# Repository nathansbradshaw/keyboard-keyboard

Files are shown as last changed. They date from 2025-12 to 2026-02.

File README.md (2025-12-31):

# Keyboard-keyboard

Keyboard-keyboard is a Hall-effect keyboard PCB. The design is based on the IBM Model M keyboard layout. But this is intended to be used as a gimicky musical keyboard.

## Acknowledgements

- Based on the work of 
  [peppapighs](https://github.com/peppapighs/HE60/tree/main) for the hall effect keyboard and [dcpedit](https://github.com/dcpedit/mod-mmm) for the Model M layout.

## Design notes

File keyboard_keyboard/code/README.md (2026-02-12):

# Getting Started with Embedded Rust

This guide will help you set up your environment for embedded development using Rust. We'll cover the installation of necessary tools and libraries, and show you how to flash your program to a microcontroller and debug it.

## Prerequisites

Ensure you have Rust installed on your system. If not, you can install it from the [official Rust website](https://www.rust-lang.org/tools/install).

## Required Libraries and Tools

1. **Add the Rust Target for ARM Cortex-M microcontrollers:**

   ```sh
   rustup target add thumbv7em-none-eabihf
   ```

2. **Add LLVM Tools:**

   ```sh
   rustup component add llvm-tools-preview
   ```

3. **Install cargo-binutils:**

   ```sh
   cargo install cargo-binutils
   ```

4. **Install cargo-embed (actually probe-rs):**

   https://probe.rs/docs/getting-started/installation/

   `cargo-embed` is used for flashing your program to the microcontroller and provides a basic debugger.

## Flashing Your Program

To flash your program to a microcontroller, navigate to your project directory in the terminal and run:

```sh
cargo xtask embed
```

This command reads your `Embed.toml` configuration file (if present) and flashes the program accordingly.

## Running the host example
```sh
cargo run -p host-target-tests --bin host-target-tests
```

## Setting Up the Debugger

### Linux

- Install `gdb-multiarch` to debug a wide range of architectures:

  ```sh
  sudo apt-get install gdb-multiarch
  ```

### Windows

- Download and install the [Arm GNU Toolchain](https://developer.arm.com/downloads/-/arm-gnu-toolchain-downloads). This package includes `arm-none-eabi-gdb`, which is the debugger for ARM microcontrollers.

### macOS

- Use Homebrew to install the ARM version of GDB:

  ```sh
  brew install arm-none-eabi-gdb
  ```

## Debugging Your Program

To start a debug session, you need a GDB server running for your specific microcontroller. This might be provided by `cargo embed`, OpenOCD, or JLinkGDBServer, depending on your setup.

1. **Start the GDB Server** (if not automatically started by `cargo embed`):

   This step varies depending on your hardware and the software you're using as a GDB server. Refer to your hardware's documentation or the documentation of the GDB server software.

2. **Connect to the GDB Server:**

   - For Linux and macOS, you can use `gdb-multiarch` or `arm-none-eabi-gdb` respectively.
   - For Windows, use the `arm-none-eabi-gdb` from the GNU Arm Toolchain.

   Open a terminal and run:

   ```sh
   gdb-multiarch target/thumbv7em-none-eabihf/debug/synth-phone-e-v2-rust
   ```

   Replace `gdb-multiarch` with `arm-none-eabi-gdb` if you're on Windows or macOS

3. **Inside GDB**, connect to the local GDB server:

   ```gdb
   target remote :1337
   ```

   The port `1337` is an example; use the port number on which your GDB server is running.

You're now ready to debug your program using GDB commands!

## Further Learning

- The [Embedded Rust Book](https://docs.rust-embedded.org/book/) is an excellent resource for learning more about embedded development with Rust.
- Check out [The Discovery Book](https://docs.rust-embedded.org/discovery/) for hands-on projects aimed at beginners.
- How the project is setup [Ferrous Systems Test Embedded App](https://ferrous-systems.com/blog/test-embedded-app/)

# File Structure
```
├── .cargo
│   └── config.toml # <- contains no build target, just command alias
├── .github
│   ├── workflows
│   │   ├── nightly.yml
│   │   ├── rustfmt.yml # <- linter
│   │   └── test.yml
├── .vscode
│   └── settings.json
├── Cargo.toml # <- outer Cargo workspace
├── autotune # <- auto tune library, can be run on host
│   ├── Cargo.toml
│   └── src
├── cross # <- Embedded workspace cannot be ran on host
│   ├── Cargo.toml # <- inner Cargo workspace
│   ├── memory.x
│   ├── .cargo
│   │   └── config.toml # <- build target for daisy seed
│   ├── app
│   ├── board
│   ├── Embed.toml
│   ├── self-tests
│   └── target
├── docs
│   ├── help.md
│   └── random_notes.md
├── host-target-tests 
│   ├── Cargo.toml
│   ├── src
│   └── tests
├── README.md
├── target
│   ├── CACHEDIR.TAG
│   └── debug
└── xtask
    ├── Cargo.toml
    └── src

```

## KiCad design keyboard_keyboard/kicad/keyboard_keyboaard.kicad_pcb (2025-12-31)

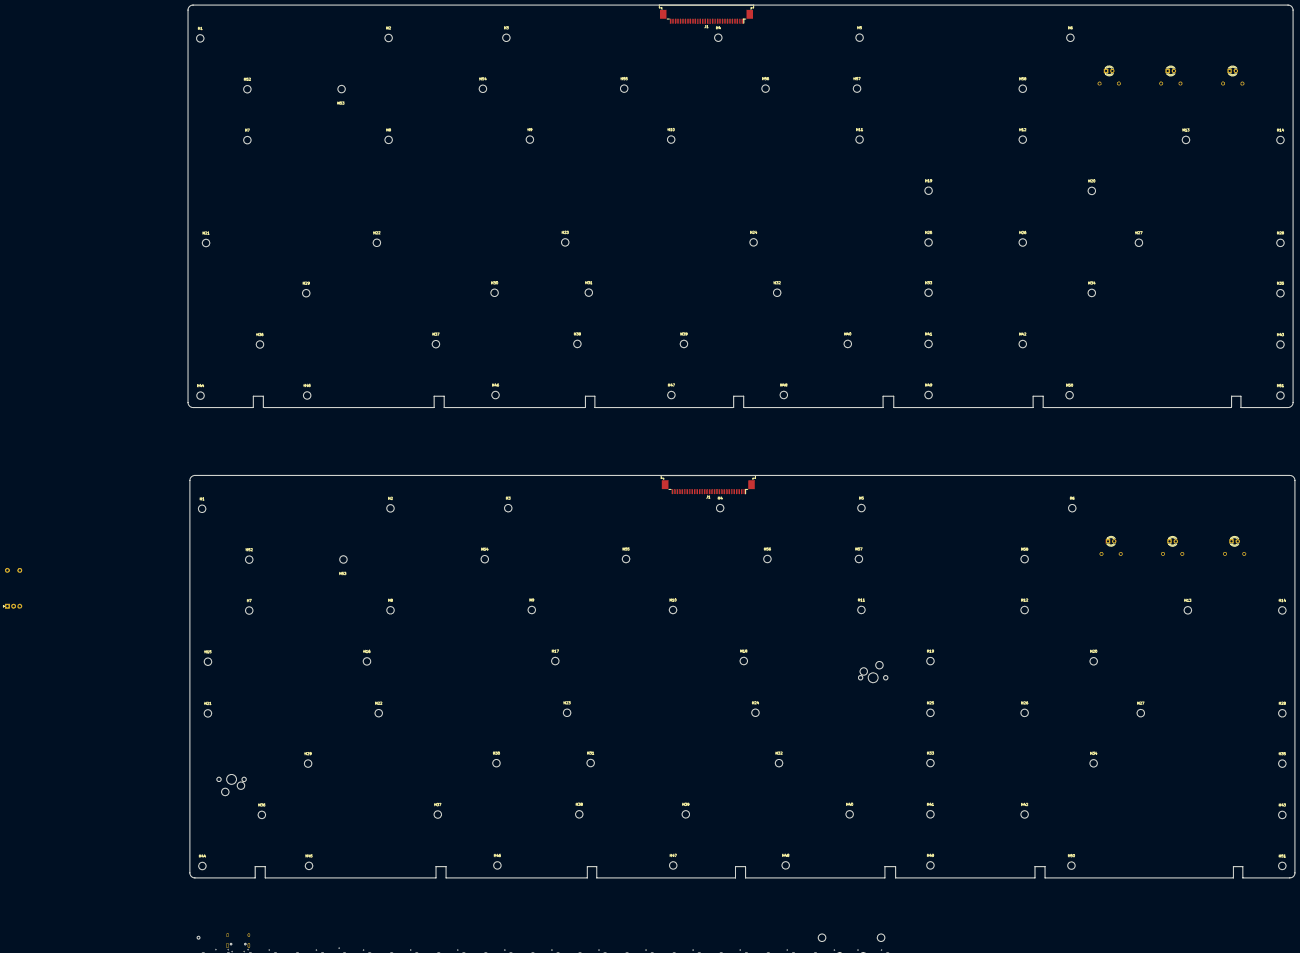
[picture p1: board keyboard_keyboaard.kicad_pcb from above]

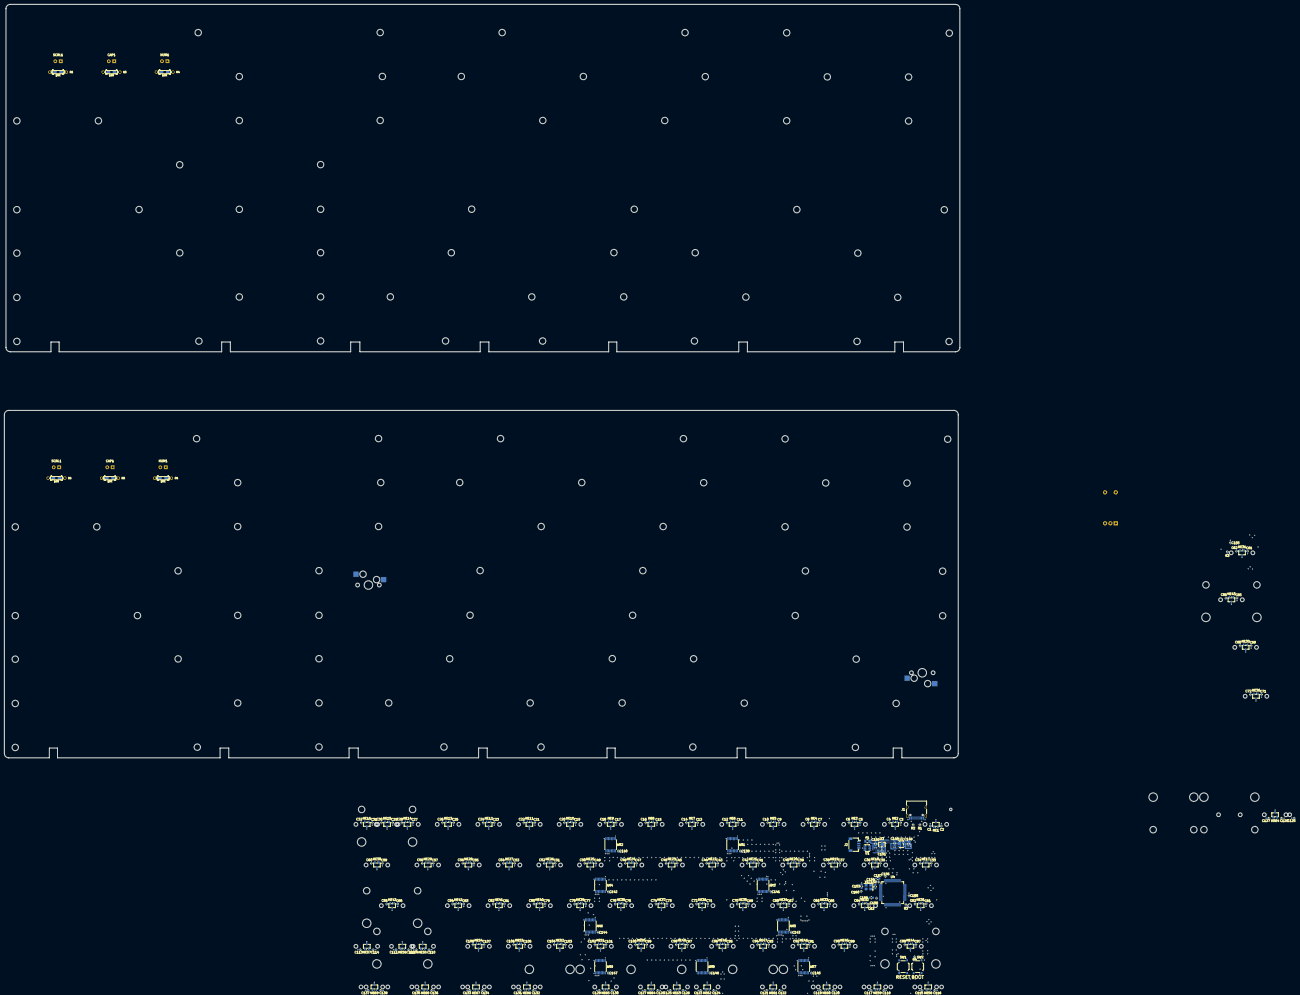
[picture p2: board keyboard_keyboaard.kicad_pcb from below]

Board: 2 copper layers, 447.8 x 353.1 mm, 484 parts (270 on the bottom side), 128 nets, no tracks yet.

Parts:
AM1, AM2, AM3, AM4, AM5, AM6, AM7, AM8, AM9: SN74LV4051A; TSSOP-16_4.4x5mm_P0.65mm
C1, C3, C5, C7, C9, C11, C13, C15, C17, C19, C21, C23, C25, C27, C29, C31, C33, C35, C37, C39, C41, C43, C45, C47, C49, C51, C53, C55, C57, C59, C59#2, C61, C61#2, C63, C65, C67, C69, C71, C71#2, C73, C75, C77, C79, C81, C83, C85, C85#2, C87, C89, C91, C93, C95, C97, C99, C101, C103, C105, C107, C109, C111, C113, C115, C117, C119, C121, C123, C125, C125#2, C127, C127#2, C129, C131, C133, C135, C137, C139, C140, C141, C142, C143, C144, C145, C146, C147, C154, C155, C155#2, C156, C158, C160: 100n; C_0402_1005Metric
C2, C4, C6, C8, C10, C12, C14, C16, C18, C20, C22, C24, C26, C28, C30, C32, C34, C36, C38, C40, C42, C44, C46, C48, C50, C52, C54, C56, C58, C60, C60#2, C62, C62#2, C64, C66, C68, C70, C72, C72#2, C74, C76, C78, C80, C82, C84, C86, C86#2, C88, C90, C92, C94, C96, C98, C100, C102, C104, C106, C108, C110, C112, C114, C116, C118, C120, C122, C124, C126, C128, C128#2, C130, C132, C134, C136, C138: 4.7n; C_0402_1005Metric
C148, C149, C150, C151: 2.2u; C_0603_1608Metric
C152, C153: 30p; C_0603_1608Metric
C157: 10u; C_0603_1608Metric
C159: 1u; C_0603_1608Metric
CAP1, CAP1#2: LED; LED_D3.0mm
F1: BSMD0805-050-24V; Fuse_0805_2012Metric
H1, H1#2, H2, H2#2, H3, H3#2, H4, H4#2, H5, H5#2, H6, H6#2, H7, H7#2, H8, H8#2, H9, H9#2, H10, H10#2, H11, H11#2, H12, H12#2, H13, H13#2, H14, H14#2, H15, H16, H17, H18, H19, H19#2, H20, H20#2, H21, H21#2, H22, H22#2, H23, H23#2, H24, H24#2, H25, H25#2, H26, H26#2, H27, H27#2, H28, H28#2, H29, H29#2, H30, H30#2, H31, H31#2, H32, H32#2, H33, H33#2, H34, H34#2, H35, H35#2, H36, H36#2, H37, H37#2, H38, H38#2, H39, H39#2, H40, H40#2, H41, H41#2, H42, H42#2, H43, H43#2, H44, H44#2, H45, H45#2, H46, H46#2, H47, H47#2, H48, H48#2, H49, H49#2, H50, H50#2, H51, H51#2, H52, H52#2, H53, H53#2, H54, H54#2, H55, H55#2, H56, H56#2, H57, H57#2, H58, H58#2: MountingHole; MountingHole_3mm
HE1, HE2, HE3, HE4, HE5, HE6, HE7, HE8, HE9, HE10, HE11, HE12, HE13, HE14, HE15, HE16, HE17, HE18, HE19, HE20, HE21, HE22, HE23, HE24, HE25, HE26, HE27, HE28, HE29, HE30, HE30#2, HE31, HE31#2, HE32, HE33, HE34, HE35, HE36, HE36#2, HE37, HE38, HE39, HE40, HE41, HE42, HE43, HE43#2, HE44, HE45, HE46, HE47, HE48, HE49, HE50, HE51, HE52, HE53, HE54, HE55, HE56, HE57, HE58, HE59, HE60, HE61, HE62, HE63, HE64, HE64#2, HE65, HE66, HE67, HE68, HE69: MT9102ET; SOT-23-3
J1, J1#2: Conn_01x30; TE_3-84952-0_1x30-1MP_P1.0mm_Horizontal
J1#3: TYPE-C-31-M-12; USB_C_Receptacle_HRO_TYPE-C-31-M-12
J2: JST_SH; JST_SH_SM04B-SRSS-TB_1x04-1MP_P1.00mm_Horizontal
MX1, MX2, MX3, MX4, MX5, MX6, MX7, MX8, MX9, MX10, MX11, MX12, MX13, MX14, MX16, MX18, MX19, MX20, MX21, MX22, MX23, MX24, MX25, MX26, MX27, MX28, MX29, MX32, MX33, MX34, MX35, MX36, MX36#2, MX37, MX38, MX39, MX40, MX41, MX42, MX45, MX46, MX47, MX48, MX49, MX50, MX51, MX52, MX53, MX54, MX57, MX61, MX64, MX69, MX73: 1U; MX-1U
MX15: 2U; MX-2U
MX17, MX30, MX30#2, MX59, MX63, MX71, MX75: 1.5U; MX-1.5U
MX31, MX31#2, MX55: 1.75U; MX-1.75U
MX040: MX-NoLED; MXOnly-1.25U-Hotswap
MX43, MX43#2, MX44: 2.25U; MX-2.25U
MX56: 2.75U; MX-2.75U
MX58, MX60, MX62, MX70, MX72, MX74, MX76: 1.25U; MX-1.25U
MX65: 2.25U; MX-2.25U-ReversedStabilizers
MX66, MX66#2: 6.25U; MX-6.25U-ReversedStabilizers
MX67, MX67#2: 7U; MX-7U-ReversedStabilizers
MX68, MX68#2: 2.75U; MX-2.75U-ReversedStabilizers
MX086: MX-NoLED; MXOnly-1.5U-Hotswap
NUM1, NUM1#2: LED; LED_D3.0mm
R1, R2: 5.1k; R_0402_1005Metric
R3, R3#2, R4#3: 12k; R_0402_1005Metric
R4, R4#2, R5, R5#2, R6, R6#2: 10K; Resistor-Hybrid-Back
SCRL1, SCRL1#2: LED; LED_D3.0mm
SW1, SW2: TS-1187A-B-A-B; SW_Push_1P1T_XKB_TS-1187A
SWR3: RotaryEncoder_Switch; RotaryEncoder_EC11_Nonplated
TH1, TH2: ToolingHole
U1: USBLC6-2SC6; SOT-23-6
U2: TLV75733PDBV; SOT-23-5
U3: XC6206P332MR-G; SOT-23-3
U4: AT32F405RCT7; LQFP-64_10x10mm_P0.5mm
Y1: X322512MSB4SI; Crystal_SMD_3225-4Pin_3.2x2.5mm

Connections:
+3.3V: C151.1, C154.1, C155.1, C155#2.1, C156.1, C157.1, SW2.2, U3.2 (VO), U4.1 (VDD), U4.36 (VDD), U4.64 (VDD)
+3.3VA: AM1.16 (VDD), AM2.16 (VDD), AM3.16 (VDD), AM4.16 (VDD), AM5.16 (VDD), AM6.16 (VDD), AM7.16 (VDD), AM8.16 (VDD), AM9.16 (VDD), C1.1, C3.1, C5.1, C7.1, C9.1, C11.1, C13.1, C15.1, C17.1, C19.1, C21.1, C23.1, C25.1, C27.1, C29.1, C31.1, C33.1, C35.1, C37.1, C39.1, C41.1, C43.1, C45.1, C47.1, C49.1, C51.1, C53.1, C55.1, C57.1, C59.1, C59#2.1, C61.1, C61#2.1, C63.1, C65.1, C67.1, C69.1, C71.1, C71#2.1, C73.1, C75.1, C77.1, C79.1, C81.1, C83.1, C85.1, C85#2.1, C87.1, C89.1, C91.1, C93.1, C95.1, C97.1, C99.1, C101.1, C103.1, C105.1, C107.1, C109.1, C111.1, C113.1, C115.1, C117.1, C119.1, C121.1, C123.1, C125.1, C125#2.1, C127.1, C127#2.1, C129.1, C131.1, C133.1, C135.1, C137.1, C139.1, C140.1, C141.1, C142.1, C143.1, C144.1, C145.1, C146.1, C147.1, C149.1, C158.1, C159.1, HE1.1 (VCC), HE2.1 (VCC), HE3.1 (VCC), HE4.1 (VCC), HE5.1 (VCC), HE6.1 (VCC), HE7.1 (VCC), HE8.1 (VCC), HE9.1 (VCC), HE10.1 (VCC), HE11.1 (VCC), HE12.1 (VCC), HE13.1 (VCC), HE14.1 (VCC), HE15.1 (VCC), HE16.1 (VCC), HE17.1 (VCC), HE18.1 (VCC), HE19.1 (VCC), HE20.1 (VCC), HE21.1 (VCC), HE22.1 (VCC), HE23.1 (VCC), HE24.1 (VCC), HE25.1 (VCC), HE26.1 (VCC), HE27.1 (VCC), HE28.1 (VCC), HE29.1 (VCC), HE30.1 (VCC), HE30#2.1 (VCC), HE31.1 (VCC), HE31#2.1 (VCC), HE32.1 (VCC), HE33.1 (VCC), HE34.1 (VCC), HE35.1 (VCC), HE36.1 (VCC), HE36#2.1 (VCC), HE37.1 (VCC), HE38.1 (VCC), HE39.1 (VCC), HE40.1 (VCC), HE41.1 (VCC), HE42.1 (VCC), HE43.1 (VCC), HE43#2.1 (VCC), HE44.1 (VCC), HE45.1 (VCC), HE46.1 (VCC), HE47.1 (VCC), HE48.1 (VCC), HE49.1 (VCC), HE50.1 (VCC), HE51.1 (VCC), HE52.1 (VCC), HE53.1 (VCC), HE54.1 (VCC), HE55.1 (VCC), HE56.1 (VCC), HE57.1 (VCC), HE58.1 (VCC), HE59.1 (VCC), HE60.1 (VCC), HE61.1 (VCC), HE62.1 (VCC), HE63.1 (VCC), HE64.1 (VCC), HE64#2.1 (VCC), HE65.1 (VCC), HE66.1 (VCC), HE67.1 (VCC), HE68.1 (VCC), HE69.1 (VCC), U2.5 (OUT), U4.13 (VDDA)
+5V: C148.1, C150.1, F1.2, U1.5 (VBUS), U2.1 (IN), U2.3 (EN), U3.3 (VI)
BOOT0: R4#3.1, SW2.1, U4.60 (PF11/BOOT0)
CAPS_LED: CAP1.2 (A), CAP1#2.2 (A), J1.29, J1#2.29
COL0: J1.28, J1#2.28, MX040.1 (COL)
COL1: J1.27, J1#2.27
COL2: J1.26, J1#2.26
COL3: J1.23, J1#2.23
COL4: J1.22, J1#2.22
COL5: J1.11, J1#2.11
COL6: J1.10, J1#2.10, MX086.1 (COL)
COL7: J1.7, J1#2.7
COL8: J1.5, J1#2.5
COL9: J1.4, J1#2.4
GND: AM1.6 (Inh), AM1.7 (VEE), AM1.8 (VSS), AM1.12 (X3), AM2.6 (Inh), AM2.7 (VEE), AM2.8 (VSS), AM3.2 (X6), AM3.6 (Inh), AM3.7 (VEE), AM3.8 (VSS), AM4.6 (Inh), AM4.7 (VEE), AM4.8 (VSS), AM5.6 (Inh), AM5.7 (VEE), AM5.8 (VSS), AM5.15 (X2), AM6.6 (Inh), AM6.7 (VEE), AM6.8 (VSS), AM7.6 (Inh), AM7.7 (VEE), AM7.8 (VSS), AM8.6 (Inh), AM8.7 (VEE), AM8.8 (VSS), AM9.6 (Inh), AM9.7 (VEE), AM9.8 (VSS), C1.2, C2.2, C3.2, C4.2, C5.2, C6.2, C7.2, C8.2, C9.2, C10.2, C11.2, C12.2, C13.2, C14.2, C15.2, C16.2, C17.2, C18.2, C19.2, C20.2, C21.2, C22.2, C23.2, C24.2, C25.2, C26.2, C27.2, C28.2, C29.2, C30.2, C31.2, C32.2, C33.2, C34.2, C35.2, C36.2, C37.2, C38.2, C39.2, C40.2, C41.2, C42.2, C43.2, C44.2, C45.2, C46.2, C47.2, C48.2, C49.2, C50.2, C51.2, C52.2, C53.2, C54.2, C55.2, C56.2, C57.2, C58.2, C59.2, C59#2.2, C60.2, C60#2.2, C61.2, C61#2.2, C62.2, C62#2.2, C63.2, C64.2, C65.2, C66.2, C67.2, C68.2, C69.2, C70.2, C71.2, C71#2.2, C72.2, C72#2.2, C73.2, C74.2, C75.2, C76.2, C77.2, C78.2, C79.2, C80.2, C81.2, C82.2, C83.2, C84.2, C85.2, C85#2.2, C86.2, C86#2.2, C87.2, C88.2, C89.2, C90.2, C91.2, C92.2, C93.2, C94.2, C95.2, C96.2, C97.2, C98.2, C99.2, C100.2, C101.2, C102.2, C103.2, C104.2, C105.2, C106.2, C107.2, C108.2, C109.2, C110.2, C111.2, C112.2, C113.2, C114.2, C115.2, C116.2, C117.2, C118.2, C119.2, C120.2, C121.2, C122.2, C123.2, C124.2, C125.2, C125#2.2, C126.2, C127.2, C127#2.2, C128.2, C128#2.2, C129.2, C130.2, C131.2, C132.2, C133.2, C134.2, C135.2, C136.2, C137.2, C138.2, C139.2, C140.2, C141.2, C142.2, C143.2, C144.2, C145.2, C146.2, C147.2, C148.2, C149.2, C150.2, C151.2, C152.2, C153.2, C154.2, C155.2, C155#2.2, C156.2, C157.2, C158.2, C159.2, C160.2, HE1.3 (GND), HE2.3 (GND), HE3.3 (GND), HE4.3 (GND), HE5.3 (GND), HE6.3 (GND), HE7.3 (GND), HE8.3 (GND), HE9.3 (GND), HE10.3 (GND), HE11.3 (GND), HE12.3 (GND), HE13.3 (GND), HE14.3 (GND), HE15.3 (GND), HE16.3 (GND), HE17.3 (GND), HE18.3 (GND), HE19.3 (GND), HE20.3 (GND), HE21.3 (GND), HE22.3 (GND), HE23.3 (GND), HE24.3 (GND), HE25.3 (GND), HE26.3 (GND), HE27.3 (GND), HE28.3 (GND), HE29.3 (GND), HE30.3 (GND), HE30#2.3 (GND), HE31.3 (GND), HE31#2.3 (GND), HE32.3 (GND), HE33.3 (GND), HE34.3 (GND), HE35.3 (GND), HE36.3 (GND), HE36#2.3 (GND), HE37.3 (GND), HE38.3 (GND), HE39.3 (GND), HE40.3 (GND), HE41.3 (GND), HE42.3 (GND), HE43.3 (GND), HE43#2.3 (GND), HE44.3 (GND), HE45.3 (GND), HE46.3 (GND), HE47.3 (GND), HE48.3 (GND), HE49.3 (GND), HE50.3 (GND), HE51.3 (GND), HE52.3 (GND), HE53.3 (GND), HE54.3 (GND), HE55.3 (GND), HE56.3 (GND), HE57.3 (GND), HE58.3 (GND), HE59.3 (GND), HE60.3 (GND), HE61.3 (GND), HE62.3 (GND), HE63.3 (GND), HE64.3 (GND), HE64#2.3 (GND), HE65.3 (GND), HE66.3 (GND), HE67.3 (GND), HE68.3 (GND), HE69.3 (GND), J1.1, J1.30, J1#2.1, J1#2.30, J1#3.A1 (GND), J1#3.A12 (GND), J1#3.B1 (GND), J1#3.B12 (GND), J1#3.S1 (SHIELD), J2.4, R1.2, R2.1, R3.1, R3#2.1, R4.2, R4#2.2, R4#3.2, R5.2, R5#2.2, R6.2, R6#2.2, SW1.2, U1.2 (GND), U2.2 (GND), U3.1 (GND), U4.12 (VSSA), U4.31 (VSS), U4.63 (VSS), Y1.2, Y1.4
HE1: AM3.15 (X2), C2.1, HE1.2 (OUT)
HE2: AM1.15 (X2), C4.1, HE2.2 (OUT)
HE3: AM1.14 (X1), C6.1, HE3.2 (OUT)
HE4: AM1.13 (X0), C8.1, HE4.2 (OUT)
HE5: AM1.1 (X4), C10.1, HE5.2 (OUT)
HE6: AM1.2 (X6), C12.1, HE6.2 (OUT)
HE7: AM1.4 (X7), C14.1, HE7.2 (OUT)
HE8: AM1.5 (X5), C16.1, HE8.2 (OUT)
HE9: AM2.1 (X4), C18.1, HE9.2 (OUT)
HE10: AM2.2 (X6), C20.1, HE10.2 (OUT)
HE11: AM2.4 (X7), C22.1, HE11.2 (OUT)
HE12: AM2.5 (X5), C24.1, HE12.2 (OUT)
HE13: AM2.15 (X2), C26.1, HE13.2 (OUT)
HE14: AM2.14 (X1), C28.1, HE14.2 (OUT)
HE15: AM2.13 (X0), C30.1, HE15.2 (OUT)
HE16: AM2.12 (X3), C32.1, HE16.2 (OUT)
HE17: AM3.14 (X1), C34.1, HE17.2 (OUT)
HE18: AM3.13 (X0), C36.1, HE18.2 (OUT)
HE19: AM3.12 (X3), C38.1, HE19.2 (OUT)
HE20: AM3.1 (X4), C40.1, HE20.2 (OUT)
HE21: AM3.4 (X7), C42.1, HE21.2 (OUT)
HE22: AM3.5 (X5), C44.1, HE22.2 (OUT)
HE23: AM4.1 (X4), C46.1, HE23.2 (OUT)
HE24: AM4.2 (X6), C48.1, HE24.2 (OUT)
HE25: AM4.4 (X7), C50.1, HE25.2 (OUT)
HE26: AM4.5 (X5), C52.1, HE26.2 (OUT)
HE27: AM4.15 (X2), C54.1, HE27.2 (OUT)
HE28: AM4.14 (X1), C56.1, HE28.2 (OUT)
HE29: AM4.13 (X0), C58.1, HE29.2 (OUT)
HE30: AM4.12 (X3), C60.1, C60#2.1, HE30.2 (OUT), HE30#2.2 (OUT)
HE31: AM7.1 (X4), C62.1, C62#2.1, HE31.2 (OUT), HE31#2.2 (OUT)
HE32: AM5.1 (X4), C64.1, HE32.2 (OUT)
HE33: AM5.2 (X6), C66.1, HE33.2 (OUT)
HE34: AM5.4 (X7), C68.1, HE34.2 (OUT)
HE35: AM5.5 (X5), C70.1, HE35.2 (OUT)
HE36: AM5.14 (X1), C72.1, C72#2.1, HE36.2 (OUT), HE36#2.2 (OUT)
HE37: AM5.13 (X0), C74.1, HE37.2 (OUT)
HE38: AM5.12 (X3), C76.1, HE38.2 (OUT)
HE39: AM6.1 (X4), C78.1, HE39.2 (OUT)
HE40: AM6.2 (X6), C80.1, HE40.2 (OUT)
HE41: AM6.4 (X7), C82.1, HE41.2 (OUT)
HE42: AM6.5 (X5), C84.1, HE42.2 (OUT)
HE43: AM6.15 (X2), C86.1, C86#2.1, HE43.2 (OUT), HE43#2.2 (OUT)
HE44: AM7.2 (X6), C88.1, HE44.2 (OUT)
HE45: AM7.4 (X7), C90.1, HE45.2 (OUT)
HE46: AM7.5 (X5), C92.1, HE46.2 (OUT)
HE47: AM8.1 (X4), C94.1, HE47.2 (OUT)
HE48: AM8.2 (X6), C96.1, HE48.2 (OUT)
HE49: AM8.4 (X7), C98.1, HE49.2 (OUT)
HE50: AM8.5 (X5), C100.1, HE50.2 (OUT)
HE51: AM9.1 (X4), C102.1, HE51.2 (OUT)
HE52: AM9.2 (X6), C104.1, HE52.2 (OUT)
HE53: AM9.4 (X7), C106.1, HE53.2 (OUT)
HE54: AM9.5 (X5), C108.1, HE54.2 (OUT)
HE55: AM6.12 (X3), C110.1, HE55.2 (OUT)
HE56: AM6.13 (X0), C112.1, HE56.2 (OUT)
HE57: AM6.14 (X1), C114.1, HE57.2 (OUT)
HE58: AM7.15 (X2), C116.1, HE58.2 (OUT)
HE59: AM7.14 (X1), C118.1, HE59.2 (OUT)
HE60: AM7.13 (X0), C120.1, HE60.2 (OUT)
HE61: AM7.12 (X3), C122.1, HE61.2 (OUT)
HE62: AM8.12 (X3), C124.1, HE62.2 (OUT)
HE63: AM8.13 (X0), C126.1, HE63.2 (OUT)
HE64: AM8.14 (X1), C128.1, C128#2.1, HE64.2 (OUT), HE64#2.2 (OUT)
HE65: AM8.15 (X2), C130.1, HE65.2 (OUT)
HE66: AM9.12 (X3), C132.1, HE66.2 (OUT)
HE67: AM9.13 (X0), C134.1, HE67.2 (OUT)
HE68: AM9.14 (X1), C136.1, HE68.2 (OUT)
HE69: AM9.15 (X2), C138.1, HE69.2 (OUT)
HEXT_IN: C152.1, U4.5 (PF0/HEXT_IN), Y1.1
HEXT_OUT: C153.1, U4.6 (PF1/HEXT_OUT), Y1.3
MUX_OUT_1: AM1.3 (X), U4.17 (PA3)
MUX_OUT_2: AM2.3 (X), U4.20 (PA4)
MUX_OUT_3: AM3.3 (X), U4.21 (PA5)
MUX_OUT_4: AM4.3 (X), U4.22 (PA6)
MUX_OUT_5: AM5.3 (X), U4.23 (PA7)
MUX_OUT_6: AM6.3 (X), U4.24 (PC4)
MUX_OUT_7: AM7.3 (X), U4.25 (PC5)
MUX_OUT_8: AM8.3 (X), U4.26 (PB0)
MUX_OUT_9: AM9.3 (X), U4.27 (PB1)
MUX_SELECT_0: AM1.11 (A), AM2.11 (A), AM3.11 (A), AM4.11 (A), AM5.11 (A), AM6.11 (A), AM7.11 (A), AM8.11 (A), AM9.11 (A), U4.9 (PC1)
MUX_SELECT_1: AM1.10 (B), AM2.10 (B), AM3.10 (B), AM4.10 (B), AM5.10 (B), AM6.10 (B), AM7.10 (B), AM8.10 (B), AM9.10 (B), U4.10 (PC2)
MUX_SELECT_2: AM1.9 (C), AM2.9 (C), AM3.9 (C), AM4.9 (C), AM5.9 (C), AM6.9 (C), AM7.9 (C), AM8.9 (C), AM9.9 (C), U4.11 (PC3)
NRST: C160.1, SW1.1, U4.7 (NRST)
NUM_LED: J1.3, J1#2.3, NUM1.2 (A), NUM1#2.2 (A)
unnamed: CAP1.1 (K), CAP1#2.1 (K), R5.1, R5#2.1
unnamed: J1#3.A5 (CC1), R1.1
unnamed: J1#3.B5 (CC2), R2.2
unnamed: NUM1.1 (K), NUM1#2.1 (K), R4.1, R4#2.1
unnamed: R6.1, R6#2.1, SCRL1.1 (K), SCRL1#2.1 (K)
unnamed: R3.2, R3#2.2, U4.33 (OTGHS1_R)
RE1: J1.9, J1#2.9
RE2: J1.8, J1#2.8
RE3: J1.6, J1#2.6
ROW0: J1.25, J1#2.25
ROW1: J1.21, J1#2.21
ROW2: J1.20, J1#2.20
ROW3: J1.19, J1#2.19
ROW4: J1.18, J1#2.18
ROW5: J1.17, J1#2.17
ROW6: J1.24, J1#2.24
ROW7: J1.16, J1#2.16
ROW8: J1.15, J1#2.15
ROW9: J1.14, J1#2.14
ROW10: J1.13, J1#2.13
ROW11: J1.12, J1#2.12
SCRL_LED: J1.2, J1#2.2, SCRL1.2 (A), SCRL1#2.2 (A)
USB_D+: U1.4 (I/O2), U4.35 (OTGHS1_D+)
USB_D-: U1.6 (I/O1), U4.34 (OTGHS1_D-)
USB_PLUG_D+: J1#3.A6 (D+), J1#3.B6 (D+), J2.3, U1.3 (I/O2)
USB_PLUG_D-: J1#3.A7 (D-), J1#3.B7 (D-), J2.2, U1.1 (I/O1)
VBUS: F1.1, J1#3.A4 (VBUS), J1#3.A9 (VBUS), J1#3.B4 (VBUS), J1#3.B9 (VBUS), J2.1

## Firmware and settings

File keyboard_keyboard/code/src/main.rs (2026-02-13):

//! hall_effect_keyboard — Daisy Seed + CD74HC4051 + A1302
//! Relative-threshold scanning with per-channel baseline calibration
//! MIDI output over USART1 at 31250 baud
#![no_main]
#![no_std]

use panic_rtt_target as _;

mod midi_sender;

#[rtic::app(
    device = stm32h7xx_hal::stm32,
    peripherals = true,
    dispatchers = [DMA1_STR2, DMA1_STR3, DMA1_STR4, DMA1_STR5, DMA1_STR6]
)]
mod app {
    const BLOCK_SIZE: usize = 128;
    const NUM_KEYS: usize = 8;
    const NUM_ACTIVE_KEYS: usize = 6;

    // Map each mux channel to a MIDI note number.
    const KEY_TO_NOTE: [u8; NUM_KEYS] = [48, 50, 52, 55, 57, 60, 62, 64];

    use crate::midi_sender::MidiSender;
    use libdaisy::gpio::*;
    use libdaisy::logger;
    use libdaisy::{audio, system};
    use stm32h7xx_hal::time::MilliSeconds;

    use libdaisy::hal::{
        adc::{self, Adc, AdcSampleTime, Resolution},
        gpio::{Analog, Output, PushPull},
        prelude::*,
        serial::{config::Config as SerialConfig, SerialExt},
        stm32,
        time::U32Ext,
        timer,
    };
    use log::info;

    // ── ADC config ─────────────────────────────────────────────────────────────
    const ADC_SAMPLE_TIME: AdcSampleTime = AdcSampleTime::T_16;
    const ADC_RESOLUTION: Resolution = Resolution::TwelveBit;

    // ── Calibration ────────────────────────────────────────────────────────────
    const CALIBRATION_SAMPLES: usize = 64;

    // ── Key thresholds (relative to per-channel baseline) ─────────────────────
    const FIRST_DELTA: u16 = 200;
    const SECOND_DELTA: u16 = 400;
    const RELEASE_DELTA: u16 = 150;

    // ── Debounce ───────────────────────────────────────────────────────────────
    // How many consecutive ticks a threshold must be exceeded before we act.
    // At 1kHz scan rate, 3 ticks = 3ms — filters out single-sample noise
    // spikes while adding negligible latency.
    const DEBOUNCE_TICKS: u8 = 3;

    // ── Moving average filter ──────────────────────────────────────────────────
    // Number of samples to average per channel. Must be a power of 2 for
    // efficient division. 4 samples = 4ms of smoothing at 1kHz.
    const FILTER_SIZE: usize = 4;
    const FILTER_SHIFT: u32 = 2; // log2(FILTER_SIZE)

    // ── Velocity ───────────────────────────────────────────────────────────────
    const VELOCITY_WINDOW_MS: u32 = 80;

    // ── Diagnostic logging ─────────────────────────────────────────────────────
    // Set to true to log raw ADC values every LOG_INTERVAL_MS.
    // Use this to see what your channels are doing at rest and find noise.
    const DIAG_LOGGING: bool = true;
    const LOG_INTERVAL_MS: u32 = 500;

    // ── Per-channel filter state ───────────────────────────────────────────────
    #[derive(Clone, Copy)]
    pub struct ChannelFilter {
        ring: [u16; FILTER_SIZE],
        index: usize,
        sum: u32,
    }

    impl ChannelFilter {
        const fn new() -> Self {
            Self {
                ring: [0; FILTER_SIZE],
                index: 0,
                sum: 0,
            }
        }

        /// Feed a new raw sample, return the filtered (averaged) value.
        fn feed(&mut self, raw: u16) -> u16 {
            // Subtract the oldest sample, add the new one
            self.sum -= self.ring[self.index] as u32;
            self.sum += raw as u32;
            self.ring[self.index] = raw;
            self.index = (self.index + 1) % FILTER_SIZE;
            (self.sum >> FILTER_SHIFT) as u16
        }

        /// Prime all slots with the same value (used after calibration).
        fn prime(&mut self, value: u16) {
            for slot in self.ring.iter_mut() {
                *slot = value;
            }
            self.sum = value as u32 * FILTER_SIZE as u32;
            self.index = 0;
        }
    }

    // ── Key state machine ──────────────────────────────────────────────────────
    #[derive(Clone, Copy, Debug)]
    pub enum KeyPhase {
        Idle,
        FirstActuated { tick: u32 },
        FullyActuated { velocity: u8 },
    }

    #[derive(Clone, Copy)]
    pub struct KeyState {
        phase: KeyPhase,
        pub last_adc: u16,
        /// Counts consecutive ticks above/below a threshold for debouncing.
        debounce_count: u8,
    }

    impl KeyState {
        const fn new() -> Self {
            Self {
                phase: KeyPhase::Idle,
                last_adc: 0,
                debounce_count: 0,
            }
        }

        fn update(
            &mut self,
            adc_value: u16,
            baseline: u16,
            tick: u32,
            key_idx: usize,
        ) -> Option<KeyEvent> {
            self.last_adc = adc_value;
            let delta = adc_value.saturating_sub(baseline);

            match self.phase {
                KeyPhase::Idle => {
                    if delta >= FIRST_DELTA {
                        self.debounce_count = self.debounce_count.saturating_add(1);
                        if self.debounce_count >= DEBOUNCE_TICKS {
                            info!(
                                "key={} FirstActuated: delta={} adc={} baseline={}",
                                key_idx, delta, adc_value, baseline
                            );
                            self.phase = KeyPhase::FirstActuated { tick };
                            self.debounce_count = 0;
                        }
                    } else {
                        self.debounce_count = 0;
                    }
                    None
                }

                KeyPhase::FirstActuated { tick: t1 } => {
                    if delta >= SECOND_DELTA {
                        self.debounce_count = self.debounce_count.saturating_add(1);
                        if self.debounce_count >= DEBOUNCE_TICKS {
                            let elapsed = tick.saturating_sub(t1);
                            info!(
                                "key={} fully actuated: delta={} elapsed={}ms",
                                key_idx, delta, elapsed
                            );

                            let velocity = if elapsed == 0 {
                                127u8
                            } else if elapsed >= VELOCITY_WINDOW_MS {
                                1u8
                            } else {
                                let v = 127u32.saturating_sub((elapsed * 126) / VELOCITY_WINDOW_MS);
                                (v + 1).min(127) as u8
                            };

                            self.phase = KeyPhase::FullyActuated { velocity };
                            self.debounce_count = 0;
                            Some(KeyEvent::NoteOn { velocity })
                        } else {
                            None
                        }
                    } else if delta < RELEASE_DELTA {
                        self.debounce_count = self.debounce_count.saturating_add(1);
                        if self.debounce_count >= DEBOUNCE_TICKS {
                            self.phase = KeyPhase::Idle;
                            self.debounce_count = 0;
                        }
                        None
                    } else {
                        // In between thresholds — reset debounce
                        self.debounce_count = 0;
                        None
                    }
                }

                KeyPhase::FullyActuated { .. } => {
                    if delta < RELEASE_DELTA {
                        self.debounce_count = self.debounce_count.saturating_add(1);
                        if self.debounce_count >= DEBOUNCE_TICKS {
                            self.phase = KeyPhase::Idle;
                            self.debounce_count = 0;
                            Some(KeyEvent::NoteOff)
                        } else {
                            None
                        }
                    } else {
                        self.debounce_count = 0;
                        None
                    }
                }
            }
        }
    }

    #[derive(Debug)]
    pub enum KeyEvent {
        NoteOn { velocity: u8 },
        NoteOff,
    }

    // ── RTIC resources ──────────────────────────────────────────────────────────
    #[shared]
    struct Shared {
        tick_ms: u32,
        key_states: [KeyState; NUM_KEYS],
        baselines: [u16; NUM_KEYS],
        event_queue: heapless::spsc::Queue<(usize, KeyEvent), 32>,
    }

    #[local]
    struct Local {
        audio: audio::Audio,
        adc: Adc<stm32::ADC1, adc::Enabled>,
        adc_pin: Daisy15<Analog>,
        s0: Daisy0<Output<PushPull>>,
        s1: Daisy1<Output<PushPull>>,
        s2: Daisy2<Output<PushPull>>,
        timer2: timer::Timer<stm32::TIM2>,
        adc_buffer: [u32; NUM_KEYS],
        midi_sender: MidiSender,
        filters: [ChannelFilter; NUM_KEYS],
    }

    // ── init ────────────────────────────────────────────────────────────────────
    #[init]
    fn init(ctx: init::Context) -> (Shared, Local, init::Monotonics) {
        logger::init();

        let mut core = ctx.core;
        let device = ctx.device;

        let ccdr = system::System::init_clocks(device.PWR, device.RCC, &device.SYSCFG);
        let mut system = libdaisy::system_init!(core, device, ccdr, BLOCK_SIZE);

        // ── GPIO (mux select lines) ─────────────────────────────────
        let mut s0 = system.gpio.daisy0.take().unwrap().into_push_pull_output();
        let mut s1 = system.gpio.daisy1.take().unwrap().into_push_pull_output();
        let mut s2 = system.gpio.daisy2.take().unwrap().into_push_pull_output();
        let mut adc_pin = system.gpio.daisy15.take().unwrap().into_analog();

        // ── ADC ──────────────────────────────────────────────────────
        let mut adc = system.adc1.enable();
        adc.set_resolution(ADC_RESOLUTION);
        adc.set_sample_time(ADC_SAMPLE_TIME);

        // Wait for power supply and sensors to fully stabilize
        cortex_m::asm::delay(480 * 50_000); // 50ms startup delay

        // ── Baseline calibration ─────────────────────────────────────
        let mut baselines = [0u16; NUM_KEYS];
        let mut filters = [ChannelFilter::new(); NUM_KEYS];

        for ch in 0..NUM_ACTIVE_KEYS {
            set_mux_channel(ch, &mut s0, &mut s1, &mut s2);
            cortex_m::asm::delay(480 * 200); // 200µs — longer settle for calibration

            let mut accumulator: u32 = 0;
            let mut sample_count = 0u32;
            for i in 0..CALIBRATION_SAMPLES {
                let result: Result<u32, _> = adc.read(&mut adc_pin);
                if let Ok(raw) = result {
                    accumulator += raw;
                    sample_count += 1;
                    if ch == 0 && i < 5 {
                        info!("calibration ch=0 sample {} raw={}", i, raw);
                    }
                }
                cortex_m::asm::delay(480 * 10);
            }
            let avg = if sample_count > 0 {
                accumulator / sample_count
            } else {
                0
            };
            baselines[ch] = avg as u16;

            // Prime the moving average filter with the baseline value
            // so it doesn't ramp up from zero on first scan.
            filters[ch].prime(avg as u16);

            info!(
                "baseline ch={} value={} (from {} samples)",
                ch, baselines[ch], sample_count
            );
        }

        // ── MIDI UART (USART1 @ 31250 baud) ─────────────────────────
        let midi_tx_pin = system
            .gpio
            .daisy13
            .take()
            .expect("Failed to get daisy13 for MIDI TX")
            .into_alternate::<7>();

        let midi_rx_pin = system
            .gpio
            .daisy14
            .take()
            .expect("Failed to get daisy14 for MIDI RX")
            .into_alternate::<7>();

        let mut midi_config = SerialConfig::default();
        midi_config.baudrate = 31_250_u32.bps();

        let midi_serial = device
            .USART1
            .serial(
                (midi_tx_pin, midi_rx_pin),
                midi_config,
                ccdr.peripheral.USART1,
                &ccdr.clocks,
            )
            .unwrap();

        let (midi_tx, _midi_rx) = midi_serial.split();
        let midi_sender = MidiSender::new(midi_tx, 0);

        // ── Timer2 @ 1 kHz ───────────────────────────────────────────
        let mut timer2 = stm32h7xx_hal::timer::TimerExt::timer(
            device.TIM2,
            MilliSeconds::from_ticks(1).into_rate(),
            ccdr.peripheral.TIM2,
            &ccdr.clocks,
        );
        timer2.listen(timer::Event::TimeOut);

        set_mux_channel(0, &mut s0, &mut s1, &mut s2);

        info!(
            "Hall effect keyboard startup done! (DIAG_LOGGING={})",
            DIAG_LOGGING
        );

        (
            Shared {
                tick_ms: 0,
                key_states: [KeyState::new(); NUM_KEYS],
                baselines,
                event_queue: heapless::spsc::Queue::new(),
            },
            Local {
                audio: system.audio,
                adc,
                adc_pin,
                s0,
                s1,
                s2,
                timer2,
                adc_buffer: [0; NUM_KEYS],
                midi_sender,
                filters,
            },
            init::Monotonics(),
        )
    }

    // ── idle ────────────────────────────────────────────────────────────────────
    #[idle]
    fn idle(_ctx: idle::Context) -> ! {
        loop {
            cortex_m::asm::nop();
        }
    }

    // ── Audio ──────────────────────────────────────────────────────────────────
    #[task(binds = DMA1_STR1, priority = 8, local = [audio])]
    fn audio_handler(ctx: audio_handler::Context) {
        ctx.local.audio.for_each(|left, right| (left, right));
    }

    // ── Timer @ 1 kHz ─────────────────────────────────────────────────────────
    #[task(
        binds = TIM2,
        local  = [timer2, adc, adc_pin, s0, s1, s2, adc_buffer, filters],
        shared = [tick_ms, key_states, baselines, event_queue],
        priority = 15
    )]
    fn timer_handler(mut ctx: timer_handler::Context) {
        ctx.local.timer2.clear_irq();

        let now = ctx.shared.tick_ms.lock(|t| {
            *t = t.wrapping_add(1);
            *t
        });

        let mut pending: heapless::Vec<(usize, KeyEvent), 8> = heapless::Vec::new();
        let baselines = ctx.shared.baselines.lock(|b| *b);

        for ch in 0..NUM_ACTIVE_KEYS {
            set_mux_channel(ch, ctx.local.s0, ctx.local.s1, ctx.local.s2);
            // Increased settle time: 10µs instead of 2µs.
            // This gives the mux output + ADC input capacitance time to
            // settle to the new channel's voltage, preventing crosstalk
            // from the previous channel bleeding into this reading.
            cortex_m::asm::delay(480 * 10);

            let result: Result<u32, _> = ctx.local.adc.read(ctx.local.adc_pin);
            if let Ok(raw) = result {
                ctx.local.adc_buffer[ch] = raw;

                // Feed through the moving average filter before threshold comparison.
                let filtered = ctx.local.filters[ch].feed(raw as u16);

                ctx.shared.key_states.lock(|states| {
                    if let Some(event) = states[ch].update(filtered, baselines[ch], now, ch) {
                        pending.push((ch, event)).ok();
                    }
                });
            }
        }

        // ── Diagnostic logging ───────────────────────────────────────
        // Every LOG_INTERVAL_MS, dump the filtered delta for every active
        // channel so you can see what's happening at rest.
        if DIAG_LOGGING && now % LOG_INTERVAL_MS == 0 {
            for ch in 0..NUM_ACTIVE_KEYS {
                let filtered = (ctx.local.filters[ch].sum >> FILTER_SHIFT) as u16;
                let delta = filtered.saturating_sub(baselines[ch]);
                let raw = ctx.local.adc_buffer[ch];
                info!(
                    "DIAG ch={} raw={} filtered={} baseline={} delta={}",
                    ch, raw, filtered, baselines[ch], delta
                );
            }
        }

        if !pending.is_empty() {
            ctx.shared.event_queue.lock(|queue| {
                for item in pending {
                    queue.enqueue(item).ok();
                }
            });
        }

        process_events::spawn().ok();
    }

    // ── Process events → send MIDI ────────────────────────────────────────────
    #[task(shared = [event_queue], local = [midi_sender], priority = 1, capacity = 32)]
    fn process_events(mut ctx: process_events::Context) {
        ctx.shared.event_queue.lock(|queue| {
            while let Some((key_idx, event)) = queue.dequeue() {
                let note = KEY_TO_NOTE[key_idx];

                match event {
                    KeyEvent::NoteOn { velocity } => {
                        info!("TX NoteOn  key={} note={} vel={}", key_idx, note, velocity);
                        ctx.local.midi_sender.note_on(note, velocity);
                    }
                    KeyEvent::NoteOff => {
                        info!("TX NoteOff key={} note={}", key_idx, note);
                        ctx.local.midi_sender.note_off(note, 0);
                    }
                }
            }
        });
    }

    // ── Helpers ───────────────────────────────────────────────────────────────
    #[inline(always)]
    fn set_mux_channel(
        ch: usize,
        s0: &mut Daisy0<Output<PushPull>>,
        s1: &mut Daisy1<Output<PushPull>>,
        s2: &mut Daisy2<Output<PushPull>>,
    ) {
        if ch & 0b001 != 0 {
            s0.set_high()
        } else {
            s0.set_low()
        }
        if ch & 0b010 != 0 {
            s1.set_high()
        } else {
            s1.set_low()
        }
        if ch & 0b100 != 0 {
            s2.set_high()
        } else {
            s2.set_low()
        }
    }
}

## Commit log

2026-02-07 chore: move files
    [keyboard_keyboaard.kicad_pcb, keyboard_keyboaard.kicad_sch]
2026-02-12 init hall effect code
2026-02-12 use correct pin
2026-02-12 keyboard velocity thing
2026-02-13 feat: better button debouncing
